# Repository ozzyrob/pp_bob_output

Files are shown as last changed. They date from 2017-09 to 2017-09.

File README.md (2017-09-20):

# pp_bob_output
 Beagleboneblack modular cnc cape system Output Board
 
To be used with pp_cape, converts 5v logic to 3v3 logic
  * Provides 8 Ouputs for Step direction (can be used for pru direct out)
  * Provides 5 Inputs ESTOP & Home\Limit switches
  * Provides 4 Outputs for relays, indicators or whatever.

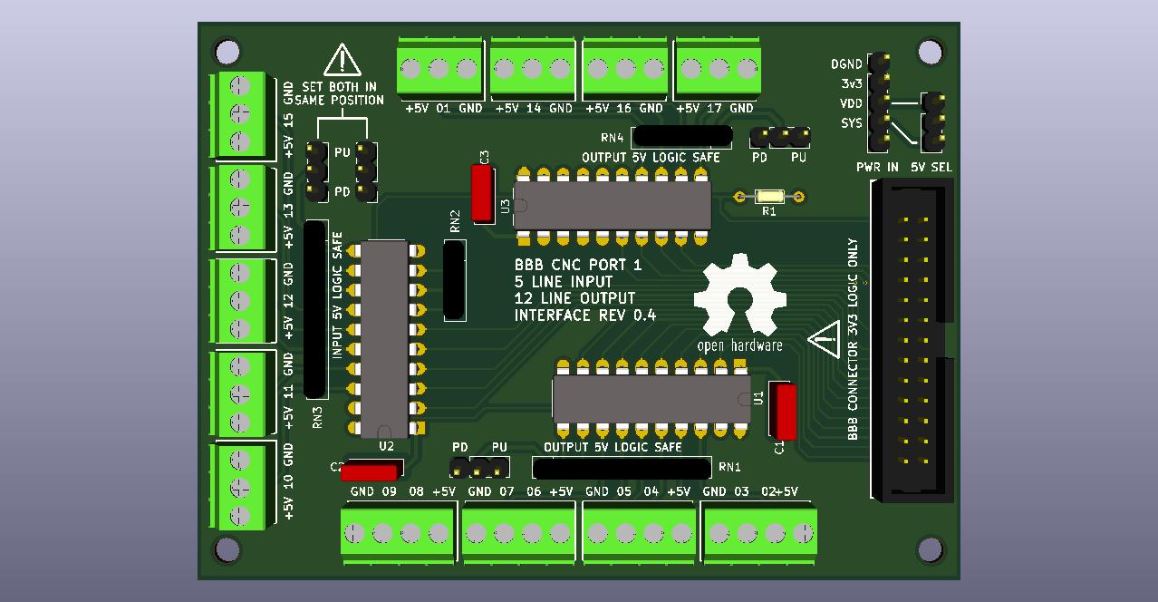
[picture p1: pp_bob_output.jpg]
output_brd


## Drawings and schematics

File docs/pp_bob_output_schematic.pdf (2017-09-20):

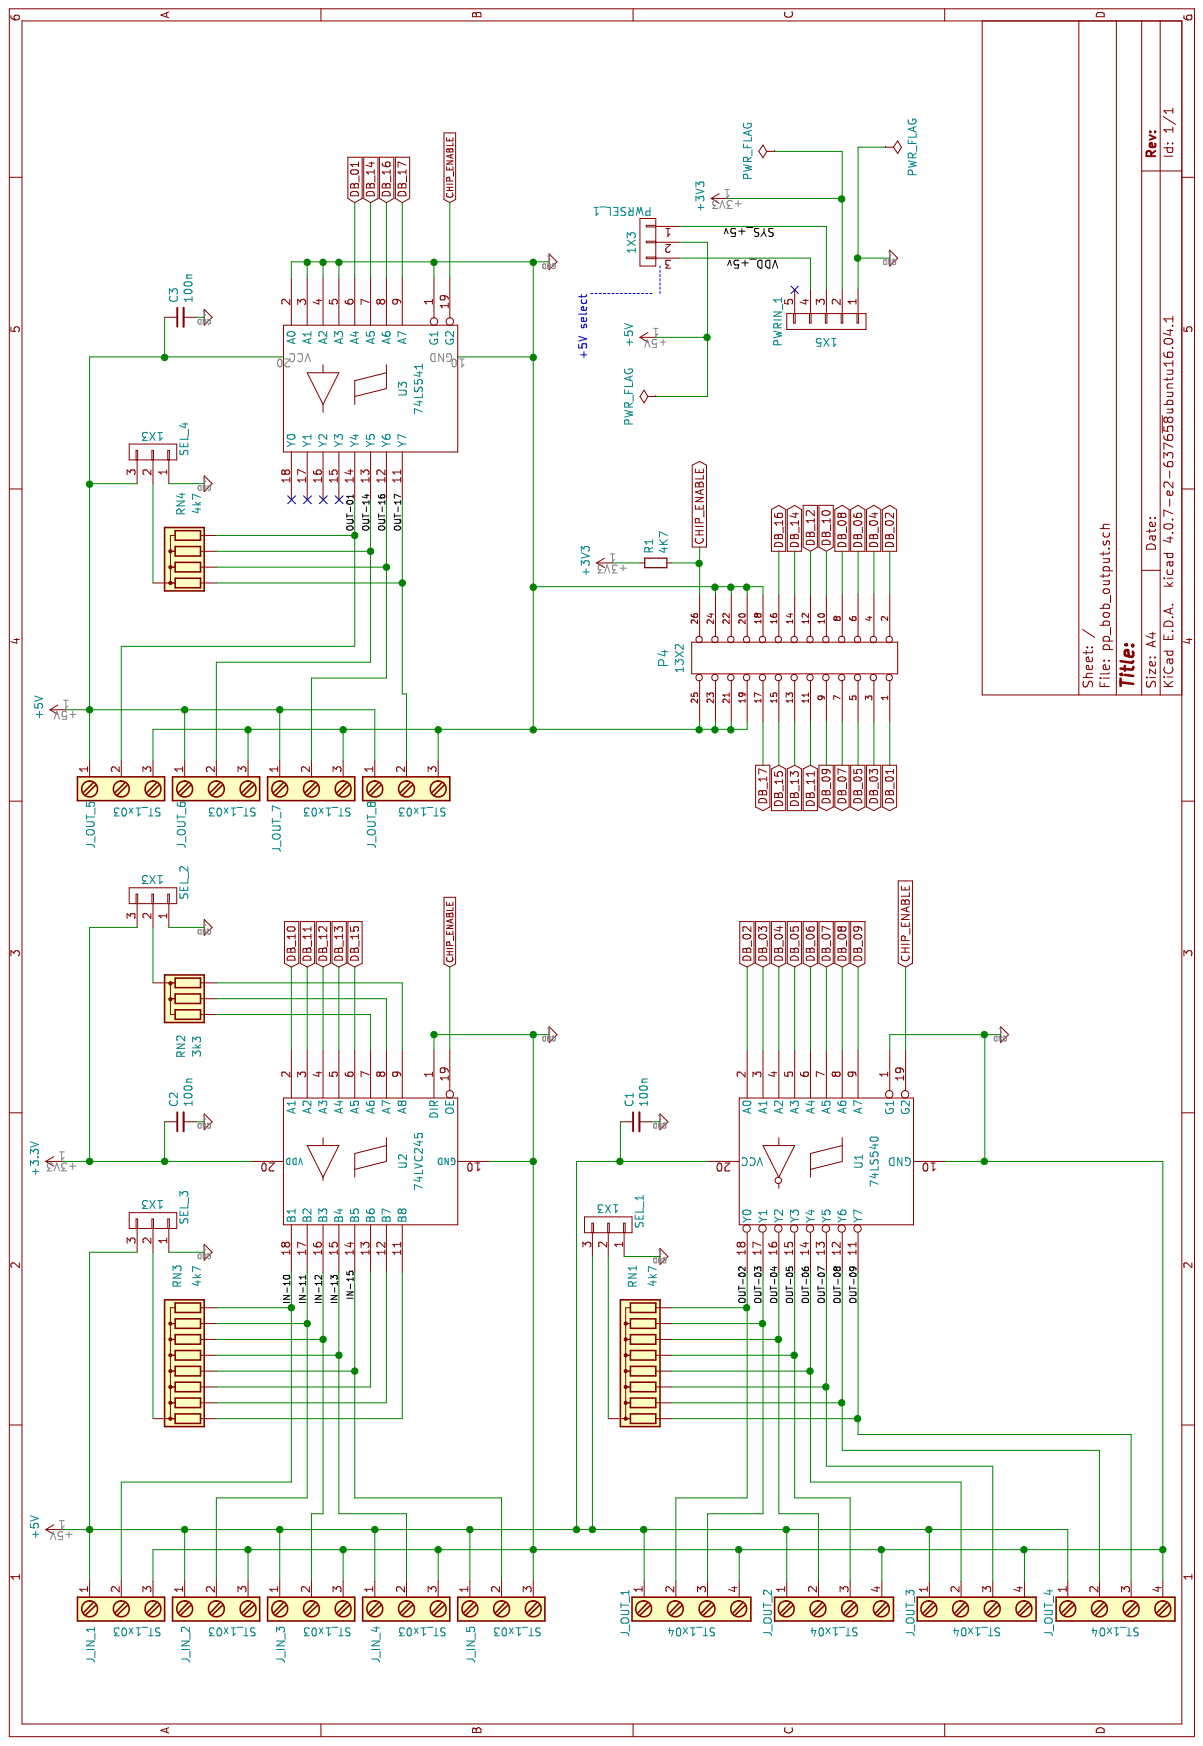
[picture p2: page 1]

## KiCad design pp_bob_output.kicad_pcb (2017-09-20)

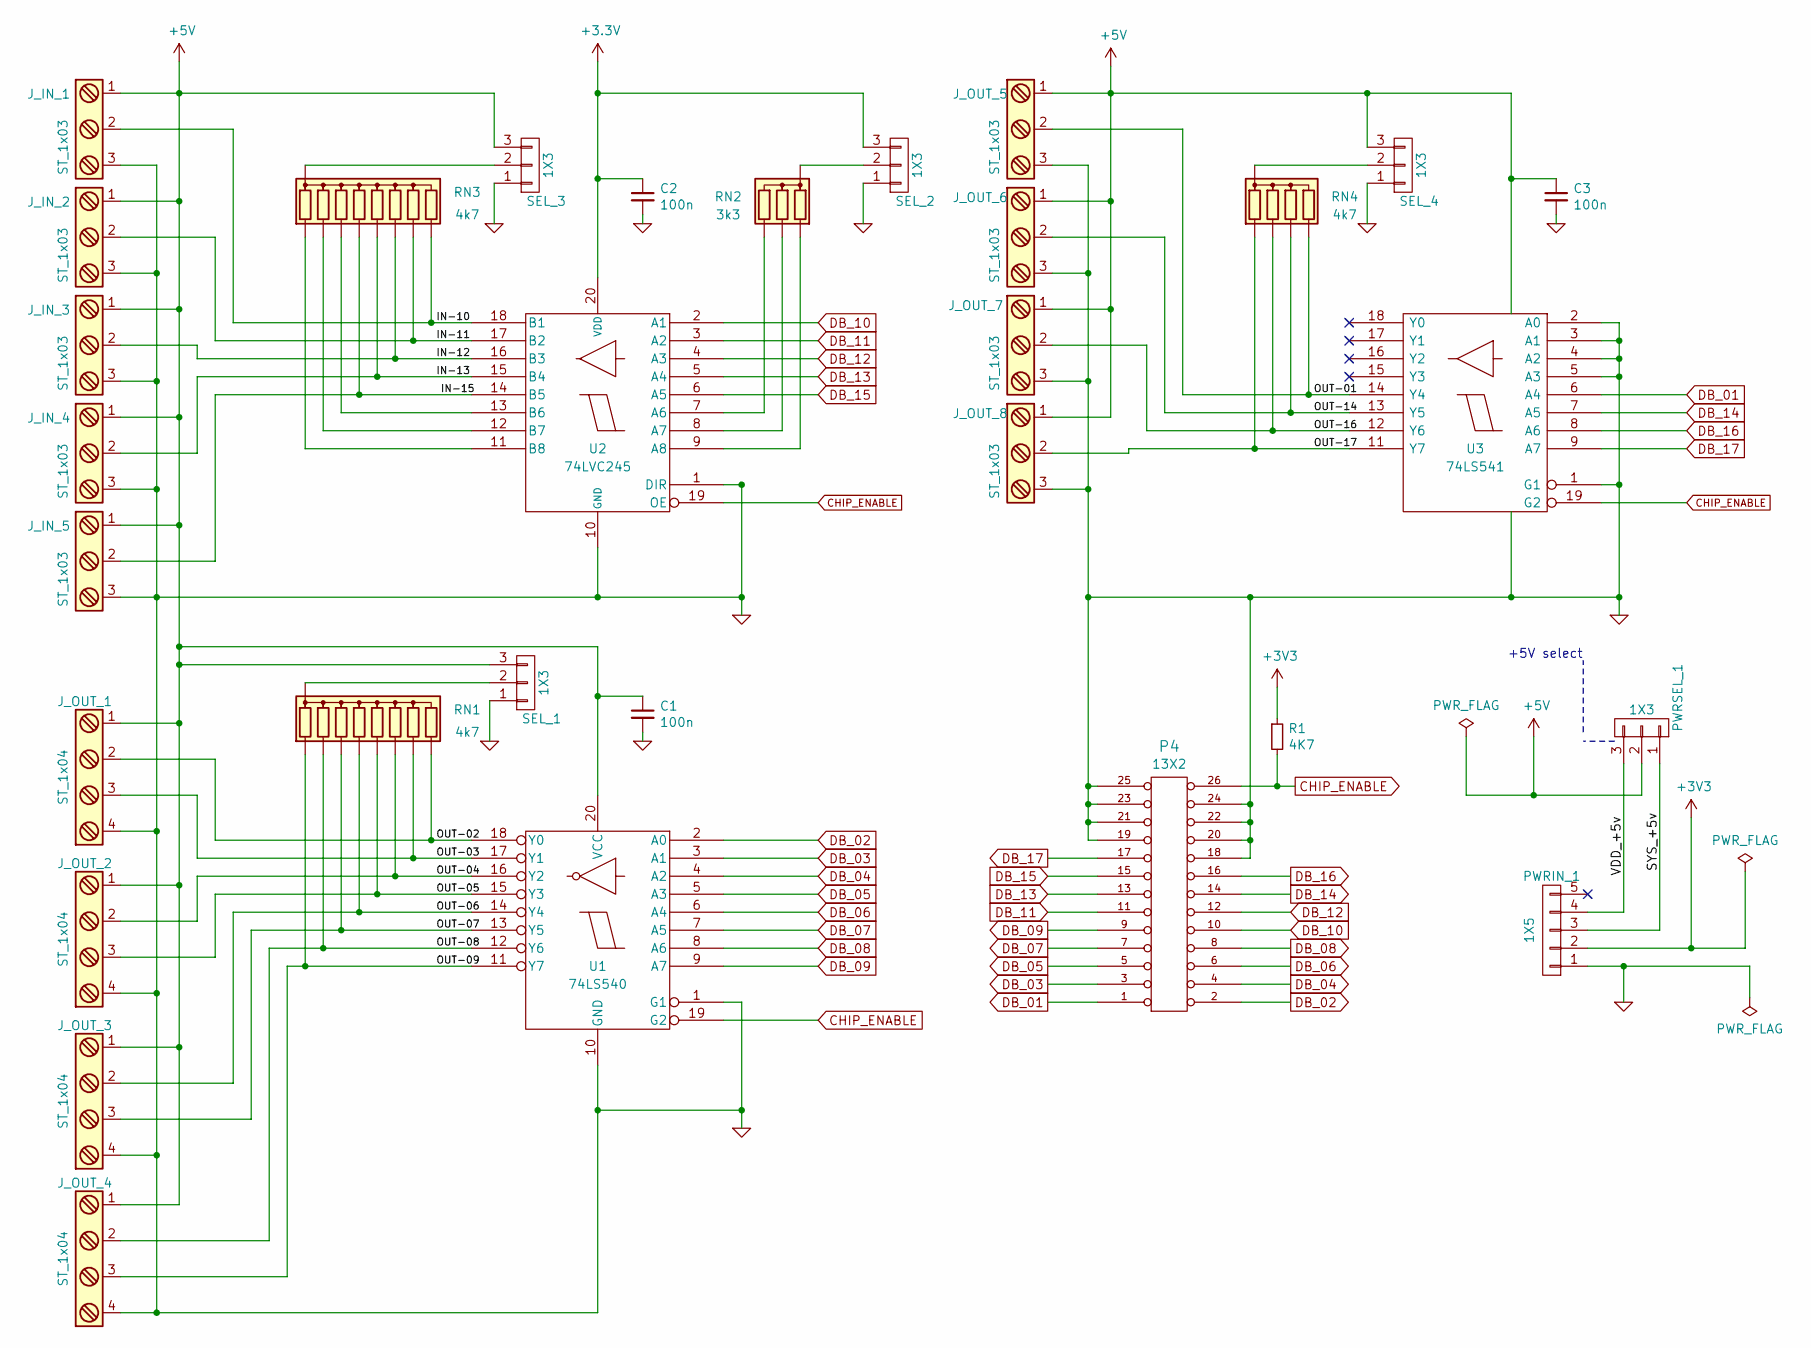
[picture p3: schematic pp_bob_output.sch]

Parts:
C1, C3: 100n; C_Rect_L7.0mm_W2.5mm_P5.00mm
C2: 100n; C_Rect_L7.0mm_W2.0mm_P5.00mm
J_IN_1, J_IN_2, J_IN_3, J_IN_4, J_IN_5: ST_1x03; pt_1,5-3-3,5-h
J_OUT_1, J_OUT_2, J_OUT_3, J_OUT_4: ST_1x04; pt_1,5-4-3,5-h
J_OUT_5, J_OUT_6, J_OUT_7, J_OUT_8: ST_1x03; pt_1,5-3-3,5-h
P4: 13X2; Pin_Header_Straight_2x13_Pitch2.54mm
PWRIN_1: 1X5; Pin_Header_Straight_1x05_Pitch2.54mm
PWRSEL_1: 1X3; Pin_Header_Straight_1x03_Pitch2.54mm
R1: 4K7; R_Axial_DIN0204_L3.6mm_D1.6mm_P7.62mm_Horizontal
RN1, RN3: 4k7; R_Array_SIP9
RN2: 3k3; R_Array_SIP4
RN4: 4k7; R_Array_SIP5
SEL_1, SEL_2, SEL_3, SEL_4: 1X3; Pin_Header_Straight_1x03_Pitch2.54mm
U1: 74LS540; DIP-20_W7.62mm_LongPads
U2: 74LVC245; DIP-20_W7.62mm_LongPads
U3: 74LS541; DIP-20_W7.62mm_LongPads

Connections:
+5V: C1.1, C3.1, J_IN_1.1, J_IN_2.1, J_IN_3.1, J_IN_4.1, J_IN_5.1, J_OUT_1.1, J_OUT_2.1, J_OUT_3.1, J_OUT_4.1, J_OUT_5.1, J_OUT_6.1, J_OUT_7.1, J_OUT_8.1, PWRSEL_1.2, SEL_1.3, SEL_3.3, SEL_4.3, U1.20 (VCC), U3.20 (VCC)
/IN-10: J_IN_1.2, RN3.9 (R8), U2.18 (B1)
/IN-11: J_IN_2.2, RN3.8 (R7), U2.17 (B2)
/IN-12: J_IN_3.2, RN3.7 (R6), U2.16 (B3)
/IN-13: J_IN_4.2, RN3.6 (R5), U2.15 (B4)
/IN-15: J_IN_5.2, RN3.5 (R4), U2.14 (B5)
/OUT-01: J_OUT_5.2, RN4.5 (R4), U3.14 (Y4)
/OUT-02: J_OUT_1.2, RN1.9 (R8), U1.18 (Y0)
/OUT-03: J_OUT_1.3, RN1.8 (R7), U1.17 (Y1)
/OUT-04: J_OUT_2.2, RN1.7 (R6), U1.16 (Y2)
/OUT-05: J_OUT_2.3, RN1.6 (R5), U1.15 (Y3)
/OUT-06: J_OUT_3.2, RN1.5 (R4), U1.14 (Y4)
/OUT-07: J_OUT_3.3, RN1.4 (R3), U1.13 (Y5)
/OUT-08: J_OUT_4.2, RN1.3 (R2), U1.12 (Y6)
/OUT-09: J_OUT_4.3, RN1.2 (R1), U1.11 (Y7)
/OUT-14: J_OUT_6.2, RN4.4 (R3), U3.13 (Y5)
/OUT-16: J_OUT_7.2, RN4.3 (R2), U3.12 (Y6)
/OUT-17: J_OUT_8.2, RN4.2 (R1), U3.11 (Y7)
/SYS_+5v: PWRIN_1.3, PWRSEL_1.1
/VDD_+5v: PWRIN_1.4, PWRSEL_1.3
CHIP_ENABLE: P4.26 (P22), R1.2, U1.19 (G2), U2.19 (OE), U3.19 (G2)
DB_01: P4.1, U3.6 (A4)
DB_02: P4.2, U1.2 (A0)
DB_03: P4.3, U1.3 (A1)
DB_04: P4.4, U1.4 (A2)
DB_05: P4.5, U1.5 (A3)
DB_06: P4.6, U1.6 (A4)
DB_07: P4.7, U1.7 (A5)
DB_08: P4.8, U1.8 (A6)
DB_09: P4.9, U1.9 (A7)
DB_10: P4.10, U2.2 (A1)
DB_11: P4.11, U2.3 (A2)
DB_12: P4.12, U2.4 (A3)
DB_13: P4.13, U2.5 (A4)
DB_14: P4.14, U3.7 (A5)
DB_15: P4.15, U2.6 (A5)
DB_16: P4.16, U3.8 (A6)
DB_17: P4.17, U3.9 (A7)
GND: C1.2, C2.2, C3.2, J_IN_1.3, J_IN_2.3, J_IN_3.3, J_IN_4.3, J_IN_5.3, J_OUT_1.4, J_OUT_2.4, J_OUT_3.4, J_OUT_4.4, J_OUT_5.3, J_OUT_6.3, J_OUT_7.3, J_OUT_8.3, P4.18, P4.19, P4.20, P4.21, P4.22, P4.23, P4.24 (P20), P4.25 (P24), PWRIN_1.1, SEL_1.1, SEL_2.1, SEL_3.1, SEL_4.1, U1.1 (G1), U1.10 (GND), U2.1 (DIR), U2.10 (GND), U3.1 (G1), U3.2 (A0), U3.3 (A1), U3.4 (A2), U3.5 (A3), U3.10 (GND)
unnamed: RN1.1 (common), SEL_1.2
unnamed: RN2.1 (common), SEL_2.2
unnamed: RN2.2 (R1), U2.9 (A8)
unnamed: RN2.3 (R2), U2.8 (A7)
unnamed: RN2.4 (R3), U2.7 (A6)
unnamed: RN3.1 (common), SEL_3.2
unnamed: RN3.2 (R1), U2.11 (B8)
unnamed: RN3.3 (R2), U2.12 (B7)
unnamed: RN3.4 (R3), U2.13 (B6)
unnamed: RN4.1 (common), SEL_4.2

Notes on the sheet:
+5V select

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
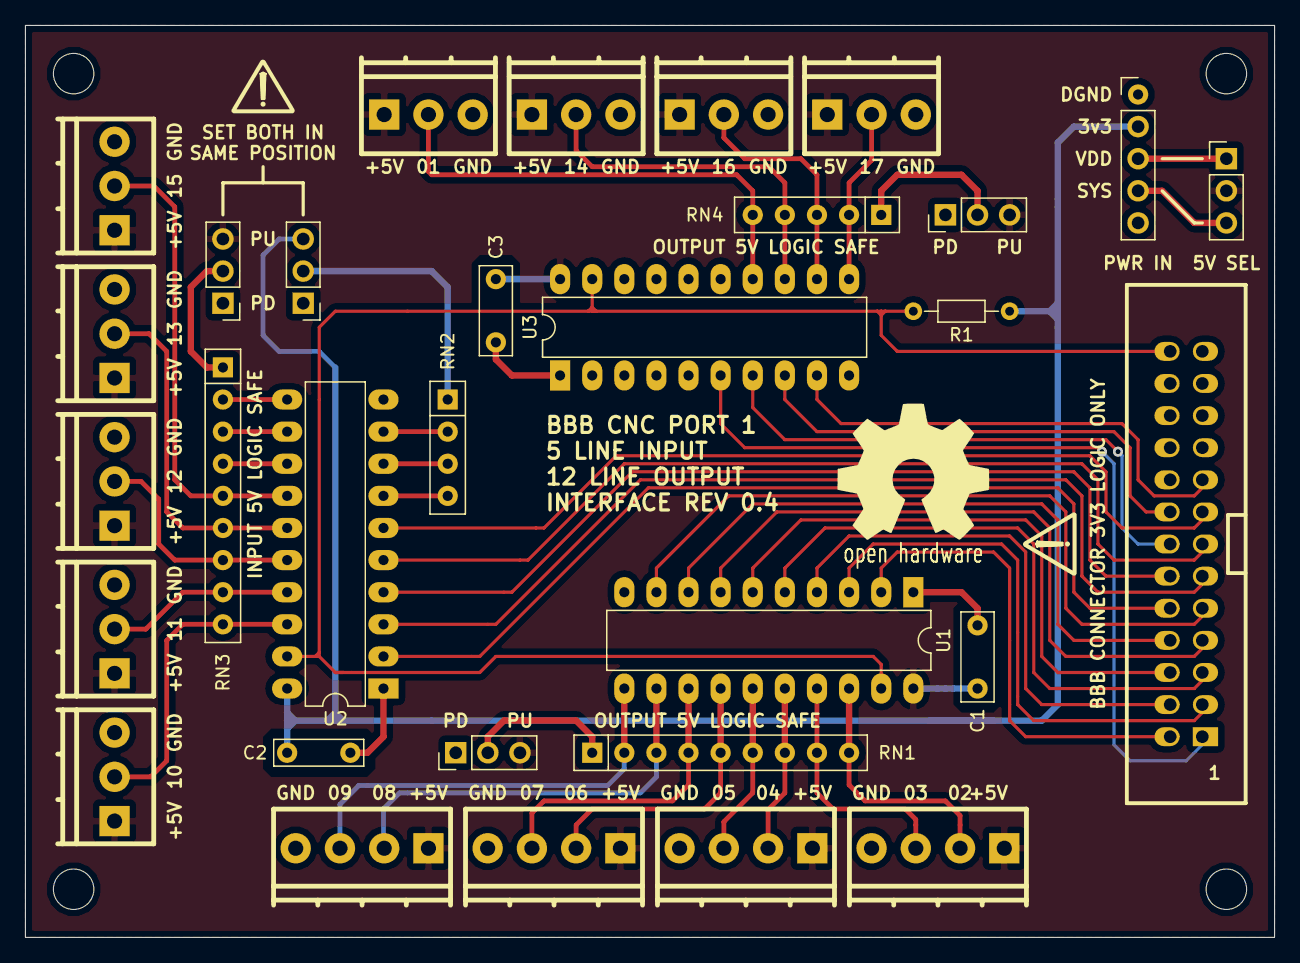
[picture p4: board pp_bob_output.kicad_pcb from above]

Board: 2 copper layers, 98.8 x 72.1 mm, 31 parts (0 on the bottom side), 50 nets.

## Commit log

2017-04-14 Inital Commit
    [pp_bob_output.kicad_pcb, pp_bob_output.sch]
2017-04-14 Initial V0.2 commit
    [pp_bob_output.kicad_pcb]
2017-04-14 Clean up in line with pp_bob_output_v0.3
    [pp_bob_output.kicad_pcb]
2017-04-14 Clean up in line with pp_bob_intput_v0.3
    [pp_bob_output.kicad_pcb]
2017-04-16 Rotated Pu-Pd headers for U2 & U3 cleaned up silkscreen
    [pp_bob_output.kicad_pcb]
2017-04-17 Cleaned up schematic
    [pp_bob_output.sch]
2017-04-23 Modified schematic for seperate termianls, PCB modded with terminals spaced equally. Tracks to be rerouted
    [pp_bob_output.kicad_pcb, pp_bob_output.sch]
2017-04-23 Fixed silkscreen & and other details, good for manu
    [pp_bob_output.kicad_pcb, pp_bob_output.sch]
2017-04-24 Adjust position of PWR IN & 5V SEL headers
    [pp_bob_output.kicad_pcb]
2017-04-24 Move 26 pin connector to allow for box type
    [pp_bob_output.kicad_pcb]
2017-04-25 Finalised for production, gerbers created, good to go
    [pp_bob_output.kicad_pcb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]
2017-04-25 Invoice & gerber zip file added.
    [pp_bob_output.kicad_pcb]
2017-09-20 Replace pp_bob_output.GBL
    [pp_bob_output.GBL]
2017-09-20 Replace pp_bob_output.GBO
    [pp_bob_output.GBO]
2017-09-20 Replace pp_bob_output.GBS
    [pp_bob_output.GBS]
2017-09-20 Replace pp_bob_output.GTL
    [pp_bob_output.GTL]
2017-09-20 Replace pp_bob_output.GTO
    [pp_bob_output.GTO]
2017-09-20 Replace pp_bob_output.GTS
    [pp_bob_output.GTS]
2017-09-20 Upload New File
    [pp_bob_output.GBL]
2017-09-20 Fix silkscreen to top
    [pp_bob_output.kicad_pcb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]
2017-09-20 Add docs
    [pp_bob_output.sch]
